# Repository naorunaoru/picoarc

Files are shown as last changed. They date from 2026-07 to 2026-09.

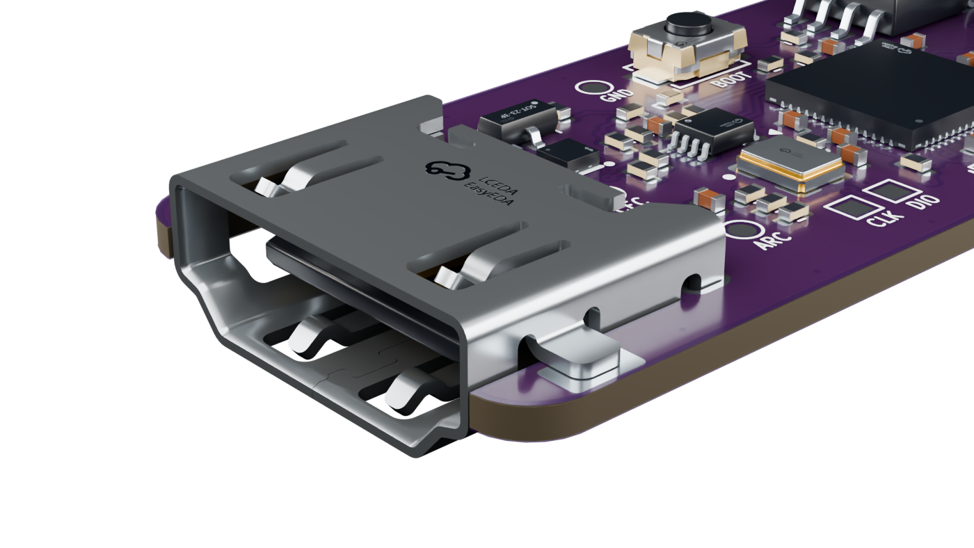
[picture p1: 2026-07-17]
assets/camera-studies/neutral-shadow-transparent/03-hdmi-macro.png

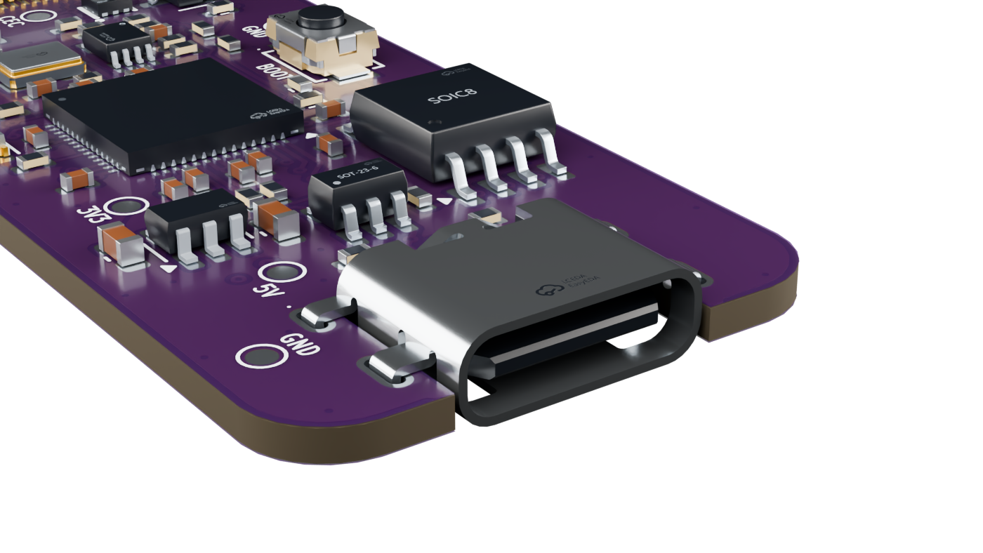
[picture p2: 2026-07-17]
assets/camera-studies/neutral-shadow-transparent/04-usbc-macro.png

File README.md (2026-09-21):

01-clean-isometric

# PicoARC

PicoARC is a device that appears to the host as a USB audio interface and passes through incoming audio as an S/PDIF-style stream to an ARC-compatible device. In simpler terms, this allows you to output audio from your computer to a soundbar or an ARC-capable receiver. It builds as USB Audio Class 1 by default for broad host compatibility; USB Audio Class 2 remains available as an opt-in target.

It also allows you to control the soundbar's volume. Somewhat. Because apparently supporting absolute volume control over CEC is not something that vendors are eager to implement.

Host volume and mute changes propagate to the soundbar in both USB modes. The
latest soundbar state is returned by subsequent USB control queries. UAC2 also
sends AudioControl change notifications; UAC1 has no notification endpoint, so
host volume controls generally remain stale after an on-device adjustment.
Host interfaces may ignore the UAC2 notifications as well.

Did I tell you it does HDMI-CEC too? Yes, it does, because it's required for ARC negotiation.

## Why?

There's no off-the-shelf way of doing this exact thing, surprisingly. The closest thing is using S/PDIF, which has limited bandwidth, sometimes incurs additional latency and definitely does not allow you to control the soundbar from the host.

## How does it work?

On the USB side, it acts as an audio interface, grabs the audio stream and passes it through.

On the HDMI side, it pretends to be a TV: responds to DDC queries with a plausible EDID, negotiates ARC with the connected audio system over CEC and drives the ARC line within the constraints defined by the HDMI 1.4 spec.

## Supported audio formats

- PCM at 32/44.1/48/88.2/96 kHz (higher sample rates are out of the question because RP2040 only has USB Full Speed)
- 16/20/24-bit

The optional UAC2 target additionally exposes separate IEC 61937 Dolby Digital
(AC-3) and DTS passthrough alternates. They are omitted from the default UAC1
target because host-driver support for Type III transport is inconsistent.

## Hardware

The PCB design lives under `hardware/`. The schematic source is written in
[Zener](https://docs.pcb.new/pages/spec), so `hardware/picoarc.zen` is the
schematic/netlist source of truth rather than a `.kicad_sch`; the KiCad layout
and JLCPCB production files are checked in alongside it.

See [hardware/README.md](hardware/README.md) for the hardware file map,
Zener/KiCad workflow, and the old hand-wired Pico prototype wiring.

## License

PicoARC uses a split license. Hardware design materials are licensed under
`CERN-OHL-W-2.0`, and firmware plus general project documentation are licensed
under `MIT`. See [LICENSE](LICENSE) for the exact scope and full license text
locations.

## Build requirements

- Git
- CMake and Ninja
- Arm GNU toolchain
- `picotool`

The Pico SDK and TinyUSB sources are pinned as git submodules under
`firmware/third_party`; builds do not use SDK copies installed on the host.
PicoARC uses Pico SDK 2.2.0 and upstream TinyUSB 0.21.0.

## Build

From this directory:

```sh
git submodule update --init --recursive
make build
```

This configures and builds both firmware variants:

```text
firmware/build-release/picoarc-release.uf2
firmware/build-debug/picoarc-debug.uf2
```

Those are UAC1 builds. To build the opt-in UAC2 target instead:

```sh
make build-uac2
```

Its artifacts use separate build directories and names so CMake and host USB
caches cannot mix the two personalities:

```text
firmware/build-release-uac2/picoarc-release-uac2.uf2
firmware/build-debug-uac2/picoarc-debug-uac2.uf2
```

UAC1 is the recommended full-speed target and is the mode tested for Windows
compatibility. Treat UAC2 as experimental on full-speed hosts; it is retained
for IEC 61937 and uses an adaptive OUT endpoint without explicit feedback. The
firmware follows the host's delivery rate by servoing the S/PDIF PIO clock from
the receive-buffer level.

The equivalent helper option is `--usb-audio-class uac2` (or `--uac uac2`),
for example `./picoarc build release --uac uac2`. Direct CMake builds can set
`-DPICOARC_USB_AUDIO_CLASS=uac2`; omitting the option selects UAC1.

By default PicoARC stops the ARC/S/PDIF carrier while USB audio is idle so the
soundbar can go to standby. To keep sending silence instead, which can prevent
short notification sounds from being swallowed while the soundbar wakes, edit
`firmware/src/picoarc_config.h` before building:

```c
#define PICOARC_IDLE_AUDIO_KEEPALIVE 1
```

Set it back to `0` for the default standby-friendly behavior.

The release variant is audio-only with logging compiled out. It waits for an
HDMI ARC device, completes ARC/SAD capability discovery, asks the soundbar for
its OSD name, and then enumerates as USB audio using that name when the soundbar
provides one. The debug variant keeps the USB serial log and reset interface
online for bring-up work, so it enumerates immediately with the default audio
descriptor.

## Host sanitizer tests

The host tests require CMake, Ninja, and a native Clang or GCC installation
with AddressSanitizer and UndefinedBehaviorSanitizer runtimes. They do not need
the Pico SDK, Arm compiler, or initialized submodules. Run them with the
default C compiler or select one before the first configure:

```sh
make test-sanitizers
CC=clang make test-sanitizers
```

The compiler selection is cached in `firmware/build-host-sanitizers`; remove
that generated directory before switching compilers. The tests compile the
same USB audio sample decoder used by the firmware and cover the supported
16-, 20-, and 24-bit subslots, including IEC 61937 words, unaligned byte input,
buffer bounds, and the maximum audio-task batch.

The RP2040 firmware remains on its normal embedded build path and is not
instrumented. Host tests cannot validate DMA and PIO timing, multicore races,
interrupt behavior, or flash-blackout behavior on the device.

## Flash

Connect the Pico over USB, then run:

```sh
make flash
```

The helper script builds the release firmware first, then uses `picotool` to
load and run the UF2. If the Pico is not detected, hold BOOTSEL while plugging
it in and run the command again.

To flash the optional UAC2 release build, use `make flash-uac2`.

## Monitor

To open the USB serial log:

```sh
make monitor
```

To build, flash, and then open the monitor in one step:

```sh
make run
```

This flashes the debug variant, because the release variant does not expose a
USB serial log.

`make run-uac2` does the same with the optional UAC2 debug build.

Press `Ctrl-]` to close the monitor.

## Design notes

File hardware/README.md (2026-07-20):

# PicoARC Hardware

The fab-ready PicoARC PCB design lives in this directory. The circuit is
authored with the [Zener](https://docs.pcb.new/pages/spec) toolchain from
[Diode](https://github.com/diodeinc/pcb), and the physical board layout is kept
as a generated/synced [KiCad](https://kicad.org/) project.

## Source of Truth

Zener is a Starlark-based hardware description language for PCB schematics. The
`pcb` CLI evaluates the `.zen` design, manages dependencies from `pcb.toml`,
assigns reference designators, validates the netlist, and generates/syncs KiCad
layout files.

In this repo, the `.zen` files are the schematic source of truth. There is no
separate `.kicad_sch` to edit:

- `picoarc.zen` is the top-level board schematic/netlist.
- `modules/` contains reusable schematic subcircuits for USB-C, power, HDMI
  ARC, and debug/status hardware.
- `components/` contains local RP2040 and flash component definitions.
- `footprints/` contains local symbols, footprints, and 3D models not taken
  directly from the upstream KiCad libraries.

Edit the Zen module tree when changing the circuit, then regenerate/sync the
KiCad layout from that source.

## Debug Probe Access

`TP_SWD` is a compact row of three 1.0 x 2.0 mm edge test pads on 1.5 mm pitch.
Connect it to Raspberry Pi Debug Probe using pogo pins or soldered leads. Its
target-side pinout is:

- pin 1: SWCLK / SC
- pin 2: GND
- pin 3: SWDIO / SD

The SWCLK and SWDIO pads currently connect directly to the RP2040. Target-side
100 ohm series termination is intentionally omitted while the board layout is
in flux and should be reconsidered before fabrication. The center ground pad
and the board's other solderable ground test pads use thermal-relief zone
connections to make hand soldering practical.

## Layout and Production Files

- `pcb.toml` is the Zener workspace/board manifest. It pins the board entry
  point, repository metadata, `pcb-version`, and KiCad library dependencies.
- `layout/layout.kicad_pro` is the KiCad project to open for board review.
- `layout/layout.kicad_pcb` is the checked-in PCB layout.
- `layout/layout.kicad_dru` contains KiCad design rules.
- `layout/jlcpcb/gerber/` contains the plotted Gerber/drill outputs.
- `layout/jlcpcb/production_files/` contains the current JLCPCB upload bundle:
  `GERBER-layout.zip`, `BOM-layout.csv`, and `CPL-layout.csv`.
- `jlcpcb-lcsc.csv` records JLCPCB/LCSC sourcing data used by the board.

## Zener/KiCad Workflow

Install the `pcb` shim using the
[upstream instructions](https://docs.pcb.new/pages/quickstart). The shim selects
the `pcbc` toolchain lane requested by `pcb.toml`; this repo currently requests
the `0.3` lane.

After changing the Zen schematic, run from this directory:

```sh
pcb sync
pcb build picoarc.zen
pcb layout picoarc.zen
```

`pcb sync` reconciles imports and dependency manifests. `pcb build` evaluates
and validates the Zener design. `pcb layout` regenerates/syncs the KiCad layout
project from the Zen netlist.

After that, open `layout/layout.kicad_pro` in KiCad for placement/routing
review, DRC, and fabrication exports. KiCad remains the tool for inspecting and
finishing the physical layout; Zener remains the tool for changing the circuit.

## Prototype Wiring

If you want to reproduce the old hand-wired Pico dev-board prototype instead,
the minimal wiring is:

- Pi Pico dev board
- HDMI breakout
- Few passives you probably have laying around
- 3.3 V <-> 5 V I2C level shifter for HDMI DDC/EDID (or not, if you're brave)

```text
Net CEC_BUS
  Pico 3V3 (pin 36)  -- R1 (27 kOhm) -- node CEC_BUS
  Pico GP3 (pin 5)   -- R2 (220 Ohm) -- node CEC_BUS
  node CEC_BUS                         -- HDMI pin 13

Net ARC_TX
  Pico GP2 (pin 4)   -- R3 (330 Ohm) -- node ATT_A
  node ATT_A         -- R4 (56 Ohm)  -- Pico GND
  node ATT_A         -- C1 (10 nF)   -- HDMI pin 14

Net HDMI_5V_FROM_SOUNDBAR
  HDMI pin 18        -- R5 (1 kOhm)   -- HDMI pin 19
  HDMI pin 18        -- R6 (68 kOhm)  -- node HDMI_5V_SENSE
  node HDMI_5V_SENSE                   -- Pico GP4 (pin 6)
  node HDMI_5V_SENSE -- R7 (100 kOhm) -- Pico GND

Net DDC_EDID
  HDMI pin 15 (SCL)  -- level shifter -- Pico GP7 (pin 10)
  HDMI pin 16 (SDA)  -- level shifter -- Pico GP6 (pin 9)

Net GND
  Pico GND (pin 38)                    -- HDMI pin 17
```

Note about DDC_EDID: while omitting a level shifter works as a bench-only direct
GPIO bodge, keep in mind that HDMI DDC is a 5 V bus and RP2040 IO is not exactly
5 V tolerant.

## License

The PicoARC hardware design materials in this directory are licensed under the
CERN Open Hardware Licence Version 2 - Weakly Reciprocal (`CERN-OHL-W-2.0`).
See [../LICENSE](../LICENSE) for the repository license notice and full license
text locations.

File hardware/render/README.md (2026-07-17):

# PicoARC product renders

The render pipeline treats `hardware/layout/layout.kicad_pcb` as the physical
source of truth. This is intentional: Zener owns the schematic/netlist, while
the checked-in KiCad PCB contains the hand-routed placement, tracks, zones,
board outline, and silkscreen used in the images.

Run from the repository root:

```sh
./hardware/render/render_pcb.py
```

The command exports the current routed PCB to a temporary STEP assembly,
refreshes the board inside `picoarc-hero.blend`, reapplies the pinned materials
and exact component models, and renders all six camera views to:

```text
assets/camera-studies/neutral-shadow-transparent/
```

The adjacent `render-manifest.json` uses repository-relative source paths and
output paths relative to the manifest. Generated PNGs and optionally saved
Blender scenes are stripped of host-specific path and runtime metadata.

The pinned default is:

- transparent RGBA background
- Neutral Shadow solder-mask/copper treatment
- neutral-loop product lighting
- Cycles with 64 samples and denoising
- 1400 x 788 PNG output
- the six named camera angles stored in the Blender template

Useful development overrides:

```sh
# Fast check of the first and HDMI views
./hardware/render/render_pcb.py --angles 1,3 --samples 16

# Render the optional charcoal-background variant
./hardware/render/render_pcb.py --background charcoal

# Save the refreshed Blender scene for inspection
./hardware/render/render_pcb.py --save-blend /tmp/picoarc-refreshed.blend
```

`render-config.json` pins the visual preset, output names, camera set, and the
baseline KiCad poses used to move the calibrated exact STEP replacements. If an
exact component is moved or rotated in KiCad, no Blender edit is necessary. If
one is moved to the opposite PCB side or its footprint/model origin changes,
the command stops and asks for that model to be recalibrated instead of
silently producing a wrong render.

Tool discovery uses `PATH` first and then the standard macOS application paths.
Use `--kicad-cli`, `--blender`, `KICAD_CLI`, or `BLENDER` to override them.

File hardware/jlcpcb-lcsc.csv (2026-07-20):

# JLCPCB LCSC overlay map for picoarc. Columns: kind | key | lcsc
# kind=mpn -> match a manufacturer part number from `pcb bom`
# kind=ref -> override by designator (wins over an mpn match)
# Seeded with the 8 ICs/connectors | then the passives/LED/MOSFET/crystal/switch (web-sourced
# from LCSC 2026-06-24 — VERIFY before ordering).
# ESD consolidation (2026-06-24): the former D2 PESD5V0L4UF (4-ch | SOT-886 | JLC shortfall +
# not LCSC-stocked) and D3 PESD5V0S2BT (2-ch) were replaced by a single 5-ch array
# (D2 D5V0M5B6LP16-7 | C445551) on the signal lines + a single TVS on the cable +5V.
# D3 cable-+5V TVS: H7VN10B (bidirectional) -> H7VH10U (UNIdirectional | C51898355
# cheaper) on 2026-06-25 — a DC rail wants a unidirectional TVS. Same R+O DFN1006-2L
# footprint (drop-in) | but polarity now matters: cathode->_HDMI_5V (verify in JLC preview).
# `make fab` WARNs and lists any still-unmapped part.
# --- ICs / connectors ---
mpn | RP2040 | C2040
mpn | PCA9306DCUR | C33196
mpn | W25Q16JVSSIQ | C131025
mpn | USBLC6-2SC6 | C7519
mpn | HC-HDMI0019T-3 | C7501810
mpn | GT-USB-7014G | C3019717
mpn | AP2112K-3.3TRG1 | C51118
# --- ESD protection ---
mpn | D5V0M5B6LP16-7 | C445551
mpn | H7VH10U | C51898355
# --- resistors (UNI-ROYAL 0402 | JLC Basic) ---
mpn | 0402WGF1000TCE | C25076
mpn | 0402WGF1001TCE | C11702
mpn | 0402WGF1002TCE | C25744
mpn | 0402WGF1003TCE | C25741
mpn | 0402WGF1200TCE | C25079
mpn | 0402WGF2003TCE | C25764
mpn | 0402WGF2200TCE | C25091
mpn | 0402WGF2201TCE | C25879
mpn | 0402WGF2202TCE | C25768
mpn | 0402WGF3300TCE | C25104
mpn | 0402WGF330JTCE | C25105
mpn | 0402WGF5101TCE | C25905
# --- capacitors ---
mpn | 0402CG101J500NT | C1546
mpn | 0402CG330J500NT | C1562
mpn | CL05A105KA5NQNC | C52923
mpn | CL05B103KB5NNNC | C15195
# next two are JLC Extended parts (per-part fee):
mpn | CL05B104KB54PNC | C307331
mpn | CL10A106MA8NRNC | C96446
# --- LED / MOSFET / crystal / switch ---
mpn | KT-0603R | C2286
mpn | 2N7002 | C8545
mpn | X322512MSB4SI | C9002
mpn | TS-1088-AR02016 | C720477

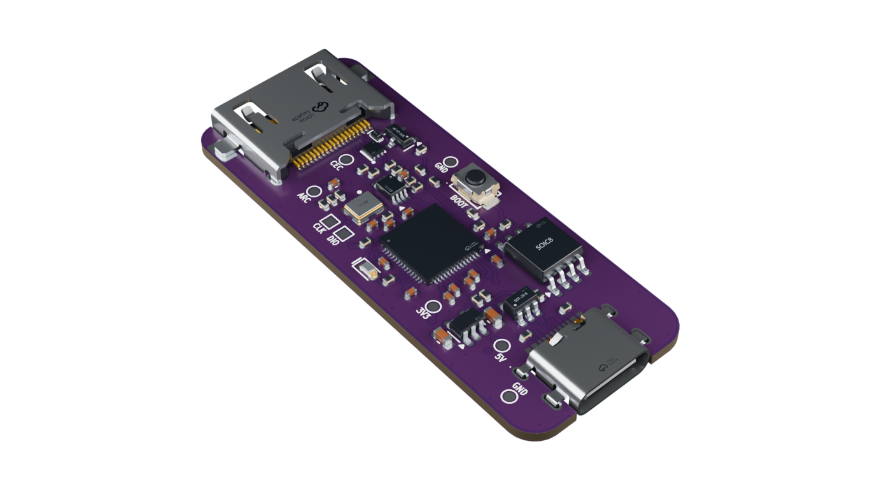
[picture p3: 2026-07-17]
assets/camera-studies/neutral-shadow-transparent/01-clean-isometric.png

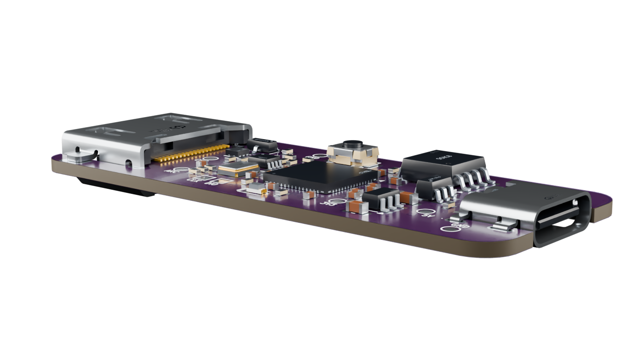
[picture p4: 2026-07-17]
assets/camera-studies/neutral-shadow-transparent/05-low-product.png

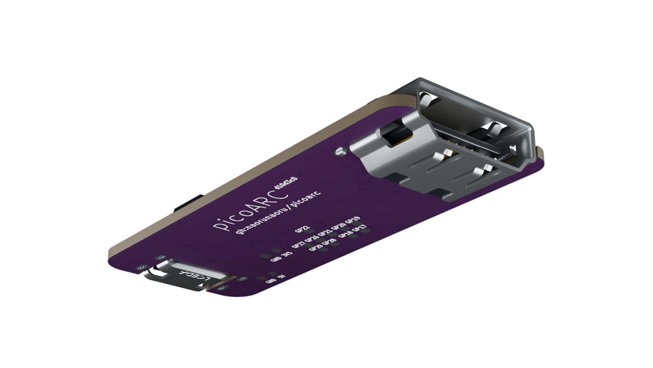
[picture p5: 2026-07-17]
assets/camera-studies/neutral-shadow-transparent/06-underside-grazing.png

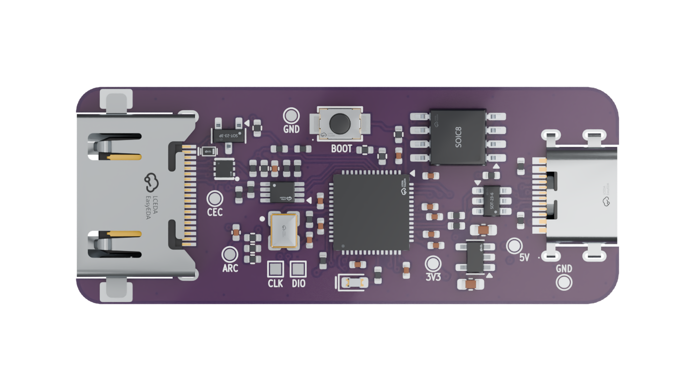
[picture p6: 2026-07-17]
assets/camera-studies/neutral-shadow-transparent/02-straight-overhead.png

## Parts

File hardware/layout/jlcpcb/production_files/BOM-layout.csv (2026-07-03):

Comment | Designator | Footprint | LCSC | Quantity
D5V0M5B6LP16-7 | D2 | DFN1616-6_L1.6-W1.6-P0.50-BL-EP | C445551 | 1
H7VH10U | D3 | SOD-882_L1.0-W0.6-BI | C7420372 | 1
TS-1088-AR02016 | SW1 | SW-SMD_L3.9-W3.0-P4.45 | C720477 | 1
0402WGF3300TCE | R3 | R_0402_1005Metric |  | 1
0402WGF1001TCE | R5 | R_0402_1005Metric |  | 1
RP2040 | U5 | QFN-56-1EP_7x7mm_P0.4mm_EP3.2x3.2mm |  | 1
0402WGF1200TCE | R15 | R_0402_1005Metric |  | 1
0402WGF2202TCE | R1 | R_0402_1005Metric |  | 1
CL05B104KB54PNC | C13 | C_0402_1005Metric |  | 1
0402WGF2201TCE | R10 | R_0402_1005Metric |  | 1
0402WGF1001TCE | R16 | R_0402_1005Metric |  | 1
CL05B104KB54PNC | C8 | C_0402_1005Metric |  | 1
CL05A105KA5NQNC | C7 | C_0402_1005Metric |  | 1
0402WGF1003TCE | R6 | R_0402_1005Metric |  | 1
CL05B104KB54PNC | C9 | C_0402_1005Metric |  | 1
CL05B104KB54PNC | C11 | C_0402_1005Metric |  | 1
0402WGF1002TCE | R20 | R_0402_1005Metric |  | 1
0402WGF1000TCE | R14 | R_0402_1005Metric |  | 1
0402WGF1001TCE | R23 | R_0402_1005Metric |  | 1
CL05B104KB54PNC | C12 | C_0402_1005Metric |  | 1
0402WGF2201TCE | R9 | R_0402_1005Metric |  | 1
0402CG330J500NT | C15 | C_0402_1005Metric |  | 1
0402CG101J500NT | C2 | C_0402_1005Metric |  | 1
0402CG330J500NT | C14 | C_0402_1005Metric |  | 1
CL05B104KB54PNC | C5 | C_0402_1005Metric |  | 1
CL05B104KB54PNC | C10 | C_0402_1005Metric |  | 1
0402WGF1003TCE | R7 | R_0402_1005Metric |  | 1
0402WGF1002TCE | R19 | R_0402_1005Metric |  | 1
0402WGF1001TCE | R4 | R_0402_1005Metric |  | 1
CL10A106MA8NRNC | C3 | C_0603_1608Metric |  | 1
CL05A105KA5NQNC | C6 | C_0402_1005Metric |  | 1
CL05B103KB5NNNC | C1 | C_0402_1005Metric |  | 1
AP2112K-3.3TRG1 | U2 | SOT-23-5 |  | 1
CL10A106MA8NRNC | C4 | C_0603_1608Metric |  | 1
2N7002 | Q1 | SOT-23 |  | 1
208658-1001 | J1 | HDMI_A_Molex_208658-1001_Horizontal |  | 1
0402WGF5101TCE | R18 | R_0402_1005Metric |  | 1
USBLC6-2SC6 | U3 | SOT-23-6 |  | 1
X322512MSB4SI | Y1 | Crystal_SMD_3225-4Pin_3.2x2.5mm |  | 1
0402WGF2200TCE | R2 | R_0402_1005Metric |  | 1
W25Q16JVSSIQ | U4 | SOIC-8_5.3x5.3mm_P1.27mm |  | 1
0402WGF330JTCE | R22 | R_0402_1005Metric |  | 1
0402WGF2003TCE | R12 | R_0402_1005Metric |  | 1
USB4105-GF-A-060 | J2 | USB_C_Receptacle_GCT_USB4105-xx-A_16P_TopMnt_Horizontal |  | 1
0402WGF1003TCE | R13 | R_0402_1005Metric |  | 1
0402WGF2201TCE | R11 | R_0402_1005Metric |  | 1
0402WGF2201TCE | R8 | R_0402_1005Metric |  | 1
0402WGF5101TCE | R17 | R_0402_1005Metric |  | 1
KT-0603R | D1 | LED_0603_1608Metric |  | 1
PCA9306DCTR | U1 | VSSOP-8_2.3x2mm_P0.5mm |  | 1
0402WGF330JTCE | R21 | R_0402_1005Metric |  | 1

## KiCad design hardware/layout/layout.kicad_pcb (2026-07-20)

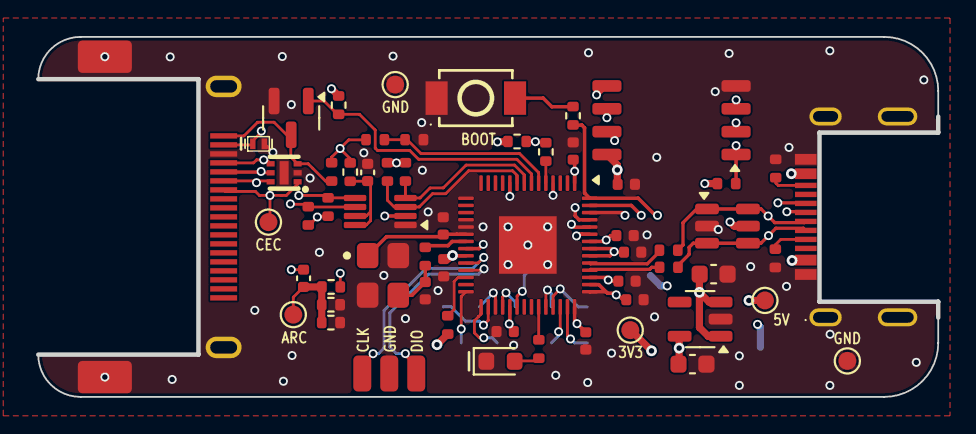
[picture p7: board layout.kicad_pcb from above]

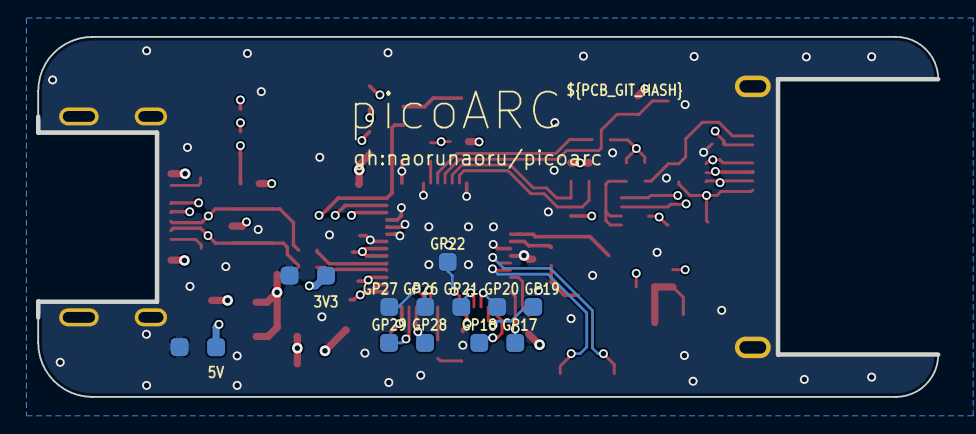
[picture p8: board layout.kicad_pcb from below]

Board: 4 copper layers, 50.0 x 20.0 mm, 72 parts (14 on the bottom side), 49 nets.

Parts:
C1: CL05B103KB5NNNC; C_0402_1005Metric
C2: 0402CG101J500NT; C_0402_1005Metric
C3, C4: CL10A106MA8NRNC; C_0603_1608Metric
C5, C8, C9, C10, C11, C12, C13: CL05B104KB54PNC; C_0402_1005Metric
C6, C7: CL05A105KA5NQNC; C_0402_1005Metric
C14, C15: 0402CG330J500NT; C_0402_1005Metric
D1: KT-0603R; LED_0603_1608Metric
D2: D5V0M5B6LP16-7; DFN1616-6_L1.6-W1.6-P0.50-BL-EP
D3: H7VH10U; SOD-882_L1.0-W0.6-BI
J1: HC-HDMI0019T-3; HDMI-SMD_HC-HDMI0019T-3_PicoARC_R6
J2: GT-USB-7014G; USB-C-SMD_GT-USB-7014D
Q1: 2N7002; SOT-23
R1: 0402WGF2202TCE; R_0402_1005Metric
R2: 0402WGF2200TCE; R_0402_1005Metric
R3: 0402WGF3300TCE; R_0402_1005Metric
R4, R5, R16, R23: 0402WGF1001TCE; R_0402_1005Metric
R6, R7, R13: 0402WGF1003TCE; R_0402_1005Metric
R8, R9, R10, R11: 0402WGF2201TCE; R_0402_1005Metric
R12: 0402WGF2003TCE; R_0402_1005Metric
R14: 0402WGF1000TCE; R_0402_1005Metric
R15: 0402WGF1200TCE; R_0402_1005Metric
R17, R18: 0402WGF5101TCE; R_0402_1005Metric
R19, R20: 0402WGF1002TCE; R_0402_1005Metric
R21, R22: 0402WGF330JTCE; R_0402_1005Metric
SW1: TS-1088-AR02016; SW-SMD_L3.9-W3.0-P4.45
TP1, TP2, TP3, TP4, TP5, TP6, TP7, TP8, TP9, TP10, TP11, TP12, TP13, TP14: ?; TestPad_1.0x1.0mm_RoundRect
TP15: ?; SWD_EdgePads_1x03_P1.50mm
TP16, TP17, TP18, TP19, TP20, TP21: ?; TestPoint_Pad_D1.0mm
U1: PCA9306DCUR; VSSOP-8_2.3x2mm_P0.5mm
U2: AP2112K-3.3TRG1; SOT-23-5
U3: USBLC6-2SC6; SOT-23-6
U4: W25Q16JVSSIQ; SOIC-8_5.3x5.3mm_P1.27mm
U5: RP2040; QFN-56-1EP_7x7mm_P0.4mm_EP3.2x3.2mm
Y1: X322512MSB4SI; Crystal_SMD_3225-4Pin_3.2x2.5mm

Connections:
ARC_TX: R3.1, U5.4
ATT_A: C1.1, R3.2, R14.1, R15.1, TP18.1
BOOTSEL_SW: R16.2, SW1.1
CEC_BUS: R2.1, U5.5
CEC_NODE: D2.1, J1.13, R1.2, R2.2, TP19.1
DBG.STATUS_LED_A: D1.2, R4.2
DDC_SCL: R8.1, U1.3, U5.9
DDC_SCL_5V: D2.5, J1.15, R10.1, U1.6
DDC_SDA: R9.1, U1.4, U5.8
DDC_SDA_5V: D2.4, J1.16, R11.1, U1.5
GND: C2.2, C3.2, C4.2, C5.2, C6.2, C7.2, C8.2, C9.2, C10.2, C11.2, C12.2, C13.2, C14.2, C15.2, D1.1, D2.2, D2.7, D3.2, J1.17, J1.SH, J2.A1, J2.A12, J2.B1, J2.B12, J2.S1, Q1.2, R7.2, R14.2, R15.2, R17.2, R18.2, SW1.2, TP3.1, TP4.1, TP15.2, TP20.1, TP21.1, U1.1, U2.2, U3.2, U4.4, U5.19, U5.57, Y1.2, Y1.4
GP17: TP5.1, U5.28
GP18: TP6.1, U5.29
GP19: TP7.1, U5.30
GP20: TP8.1, U5.31
GP21: TP9.1, U5.32
GP22: TP10.1, U5.34
GP26: TP11.1, U5.38
GP27: TP12.1, U5.39
GP28: TP13.1, U5.40
GP29: TP14.1, U5.41
HDMI._ARC14: C1.2, D2.6, J1.14
HDMI._HDMI_5V: D3.1, J1.18, R5.1, R6.1, R10.2, R11.2, R12.1
HDMI._HPD: D2.3, J1.19, Q1.3, R5.2
HDMI._VREF2_EN: C2.1, R12.2, U1.7, U1.8
HDMI_5V_SENSE: R6.2, R7.1, U5.6
HPD_GATE: Q1.1, R13.1, U5.7
QSPI_CLK: U4.6, U5.52
QSPI_CS: R16.1, R19.1, U4.1, U5.56
QSPI_IO0: U4.5, U5.53
QSPI_IO1: U4.2, U5.55
QSPI_IO2: U4.3, U5.54
QSPI_IO3: U4.7, U5.51
RUN: R20.1, U5.26
STATUS_LED: R4.1, U5.37
SWD_SWCLK: TP15.1, U5.24
SWD_SWDIO: TP15.3, U5.25
USBC.CC1: J2.A5, R17.1
USBC.CC2: J2.B5, R18.1
USB_D_N: J2.A7, J2.B7, R21.2, U3.3, U3.4
USB_D_P: J2.A6, J2.B6, R22.2, U3.1, U3.6
U_MCU.RP_USB_D_N: R21.1, U5.46
U_MCU.RP_USB_D_P: R22.1, U5.47
U_MCU._R_OSC: C15.1, R23.1, Y1.3
U_MCU.oscpair_XIN: C14.1, U5.20, Y1.1
U_MCU.oscpair_XOUT: R23.2, U5.21
VDD_1V1: C6.1, C8.1, C9.1, U5.23, U5.45, U5.50
VDD_3V3: C4.1, C5.1, C7.1, C10.1, C11.1, C12.1, C13.1, R1.1, R8.2, R9.2, R13.2, R19.2, R20.2, TP1.1, TP16.1, U1.2, U2.5, U4.8, U5.1, U5.10, U5.22, U5.33, U5.42, U5.43, U5.44, U5.48, U5.49
VDD_5V: C3.1, J2.A4, J2.A9, J2.B4, J2.B9, TP2.1, TP17.1, U2.1, U2.3, U3.5

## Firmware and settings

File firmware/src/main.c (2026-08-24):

#include <stdio.h>

#include "arc.h"
#include "cec.h"
#include "ddc_edid.h"
#include "hardware/gpio.h"
#include "hardware/pwm.h"
#include "hardware/watchdog.h"
#include "picoarc_config.h"
#include "picoarc_log.h"
#include "pico/stdlib.h"
#include "spdif.h"
#include "tusb.h"
#include "usb_audio.h"
#include "usb_descriptors.h"

#define STATUS_LED_PWM_WRAP 255

typedef enum {
    ADAPTER_STATE_BOOT,
    ADAPTER_STATE_WAIT_HDMI,
    ADAPTER_STATE_CEC_SCAN,
    ADAPTER_STATE_CEC_DISCOVER,
    ADAPTER_STATE_ARC_INIT,
    ADAPTER_STATE_QUERY_CAPS,
    ADAPTER_STATE_USB_ATTACH,
    ADAPTER_STATE_USB_IDLE,
    ADAPTER_STATE_USB_STREAMING,
    ADAPTER_STATE_USB_DETACH,
    ADAPTER_STATE_USB_RECOVERY,
#if PICOARC_DEBUG_USB
    ADAPTER_STATE_DEBUG_USB,
#endif
} adapter_state_t;

typedef enum {
    STATUS_LED_OFF,
    STATUS_LED_WAIT_HDMI,
    STATUS_LED_WAIT_USB,
} status_led_mode_t;

static absolute_time_t usb_recovery_reconnect_at;

static void cec_yield_pump(void) {
    tud_task();
    usb_audio_task();
}

static spdif_mode_t idle_spdif_mode(void) {
#if PICOARC_IDLE_AUDIO_KEEPALIVE
    return SPDIF_MODE_SILENCE;
#else
    return SPDIF_MODE_OFF;
#endif
}

#if PICOARC_HPD_GATE_ENABLE
static void hpd_gate_hold(unsigned int gate_pin) {
    gpio_init(gate_pin);
    gpio_put(gate_pin, true);
    gpio_set_dir(gate_pin, GPIO_OUT);
    printf("hpd: holding low through GP%u gate\n", gate_pin);
}

static void hpd_gate_release(unsigned int gate_pin) {
    gpio_put(gate_pin, false);
    printf("hpd: released GP%u gate\n", gate_pin);
}
#endif

static const char *adapter_state_name(adapter_state_t state) {
    switch (state) {
    case ADAPTER_STATE_BOOT:
        return "boot";
    case ADAPTER_STATE_WAIT_HDMI:
        return "wait-hdmi";
    case ADAPTER_STATE_CEC_SCAN:
        return "cec-scan";
    case ADAPTER_STATE_CEC_DISCOVER:
        return "cec-discover";
    case ADAPTER_STATE_ARC_INIT:
        return "arc-init";
    case ADAPTER_STATE_QUERY_CAPS:
        return "query-caps";
    case ADAPTER_STATE_USB_ATTACH:
        return "usb-attach";
    case ADAPTER_STATE_USB_IDLE:
        return "usb-idle";
    case ADAPTER_STATE_USB_STREAMING:
        return "usb-streaming";
    case ADAPTER_STATE_USB_DETACH:
        return "usb-detach";
    case ADAPTER_STATE_USB_RECOVERY:
        return "usb-recovery";
#if PICOARC_DEBUG_USB
    case ADAPTER_STATE_DEBUG_USB:
        return "debug-usb";
#endif
    default:
        return "unknown";
    }
}

static void adapter_set_state(adapter_state_t *state, adapter_state_t next) {
    if (*state == next) {
        return;
    }

    printf("adapter: %s -> %s\n", adapter_state_name(*state), adapter_state_name(next));
    *state = next;
}

static void adapter_task(adapter_state_t *state, bool *usb_attached) {
    if (usb_audio_take_recovery_request()) {
        usb_audio_stop_streaming();
        if (*usb_attached) {
            tud_disconnect();
            *usb_attached = false;
        }
        usb_recovery_reconnect_at = make_timeout_time_ms(PICOARC_USB_RECOVERY_DISCONNECT_MS);
        printf("adapter: forcing USB re-enumeration after stalled audio stream\n");
        adapter_set_state(state, ADAPTER_STATE_USB_RECOVERY);
    }

#if PICOARC_DEBUG_USB
    if (*state == ADAPTER_STATE_DEBUG_USB) {
        usb_audio_task();
        return;
    }
#endif

    const bool hdmi_connected = arc_hdmi_connected();
    const bool audio_system_found = arc_cec_audio_system_found();
    const bool arc_initiated = arc_is_initiated();
    const bool caps_ready = arc_audio_caps_ready();
    const bool usb_ready = arc_ready_for_usb();

    if (*state >= ADAPTER_STATE_USB_ATTACH && *state <= ADAPTER_STATE_USB_STREAMING && !usb_ready) {
        adapter_set_state(state, ADAPTER_STATE_USB_DETACH);
    }

    switch (*state) {
    case ADAPTER_STATE_BOOT:
        adapter_set_state(state, ADAPTER_STATE_WAIT_HDMI);
        break;

    case ADAPTER_STATE_WAIT_HDMI:
        if (hdmi_connected) {
            adapter_set_state(state, ADAPTER_STATE_CEC_SCAN);
        }
        break;

    case ADAPTER_STATE_CEC_SCAN:
        if (!hdmi_connected) {
            adapter_set_state(state, ADAPTER_STATE_WAIT_HDMI);
        } else if (audio_system_found) {
            adapter_set_state(state, ADAPTER_STATE_CEC_DISCOVER);
        }
        break;

    case ADAPTER_STATE_CEC_DISCOVER:
        if (!hdmi_connected) {
            adapter_set_state(state, ADAPTER_STATE_WAIT_HDMI);
        } else if (!audio_system_found) {
            adapter_set_state(state, ADAPTER_STATE_CEC_SCAN);
        } else if (arc_system_audio_enabled() || arc_initiated) {
            adapter_set_state(state, ADAPTER_STATE_ARC_INIT);
        }
        break;

    case ADAPTER_STATE_ARC_INIT:
        if (!hdmi_connected) {
            adapter_set_state(state, ADAPTER_STATE_WAIT_HDMI);
        } else if (!audio_system_found) {
            adapter_set_state(state, ADAPTER_STATE_CEC_SCAN);
        } else if (arc_initiated) {
            adapter_set_state(state, ADAPTER_STATE_QUERY_CAPS);
        }
        break;

    case ADAPTER_STATE_QUERY_CAPS:
        if (!hdmi_connected) {
            adapter_set_state(state, ADAPTER_STATE_WAIT_HDMI);
        } else if (usb_ready) {
            adapter_set_state(state, ADAPTER_STATE_USB_ATTACH);
        } else if (!arc_initiated) {
            adapter_set_state(state, ADAPTER_STATE_ARC_INIT);
        } else if (!caps_ready) {
            break;
        }
        break;

    case ADAPTER_STATE_USB_ATTACH:
        if (!*usb_attached) {
            tud_connect();
            *usb_attached = true;
            printf("adapter: USB audio attached to host\n");
        }
        adapter_set_state(state, ADAPTER_STATE_USB_IDLE);
        break;

    case ADAPTER_STATE_USB_IDLE:
        usb_audio_task();
        if (usb_audio_is_streaming()) {
            adapter_set_state(state, ADAPTER_STATE_USB_STREAMING);
        }
        break;

    case ADAPTER_STATE_USB_STREAMING:
        usb_audio_task();
        if (!usb_audio_is_streaming()) {
            adapter_set_state(state, ADAPTER_STATE_USB_IDLE);
        }
        break;

    case ADAPTER_STATE_USB_DETACH:
        usb_audio_stop_streaming();
        if (*usb_attached) {
            tud_disconnect();
            *usb_attached = false;
            printf("adapter: USB audio detached from host\n");
        }
        if (!hdmi_connected) {
            adapter_set_state(state, ADAPTER_STATE_WAIT_HDMI);
        } else if (!audio_system_found) {
            adapter_set_state(state, ADAPTER_STATE_CEC_SCAN);
        } else if (!arc_initiated) {
            adapter_set_state(state, ADAPTER_STATE_ARC_INIT);
        } else {
            adapter_set_state(state, ADAPTER_STATE_QUERY_CAPS);
        }
        break;

    case ADAPTER_STATE_USB_RECOVERY:
        if (!time_reached(usb_recovery_reconnect_at)) {
            break;
        }
#if PICOARC_DEBUG_USB
        tud_connect();
        *usb_attached = true;
        printf("adapter: USB audio reattached to host\n");
        adapter_set_state(state, ADAPTER_STATE_DEBUG_USB);
#else
        adapter_set_state(state, ADAPTER_STATE_QUERY_CAPS);
#endif
        break;

#if PICOARC_DEBUG_USB
    case ADAPTER_STATE_DEBUG_USB:
        break;
#endif
    }
}

static void status_led_set_gpio(uint led_pin, bool *led_on, bool on) {
    if (*led_on == on) {
        return;
    }

    *led_on = on;
    gpio_put(led_pin, on);
}

static void status_led_enable_pwm(uint led_pin) {
    const uint slice = pwm_gpio_to_slice_num(led_pin);
    const uint channel = pwm_gpio_to_channel(led_pin);

    gpio_set_function(led_pin, GPIO_FUNC_PWM);
    pwm_set_wrap(slice, STATUS_LED_PWM_WRAP);
    pwm_set_chan_level(slice, channel, 0);
    pwm_set_enabled(slice, true);
}

static void status_led_disable_pwm(uint led_pin) {
    const uint slice = pwm_gpio_to_slice_num(led_pin);
    const uint channel = pwm_gpio_to_channel(led_pin);

    pwm_set_chan_level(slice, channel, 0);
    pwm_set_enabled(slice, false);
    gpio_set_function(led_pin, GPIO_FUNC_SIO);
    gpio_set_dir(led_pin, GPIO_OUT);
    gpio_put(led_pin, false);
}

static uint16_t status_led_breath_level(uint32_t elapsed_ms) {
    const uint32_t phase_ms = elapsed_ms % PICOARC_STATUS_LED_WAIT_USB_BREATHE_MS;
    const uint32_t half_ms = PICOARC_STATUS_LED_WAIT_USB_BREATHE_MS / 2;
    const uint32_t ramp_ms = phase_ms < half_ms ? phase_ms : PICOARC_STATUS_LED_WAIT_USB_BREATHE_MS - phase_ms;
    const uint32_t linear = (ramp_ms * STATUS_LED_PWM_WRAP) / half_ms;

    return (uint16_t)((linear * linear) / STATUS_LED_PWM_WRAP);
}

static void status_led_update_breath(uint led_pin, uint32_t started_ms) {
    const uint slice = pwm_gpio_to_slice_num(led_pin);
    const uint channel = pwm_gpio_to_channel(led_pin);
    const uint32_t elapsed_ms = to_ms_since_boot(get_absolute_time()) - started_ms;

    pwm_set_chan_level(slice, channel, status_led_breath_level(elapsed_ms));
}

static void status_led_task(uint led_pin,
                            status_led_mode_t mode,
                            status_led_mode_t *active_mode,
                            bool *led_on,
                            absolute_time_t *next_transition,
                            uint32_t *breath_started_ms) {
    if (*active_mode != mode) {
        if (*active_mode == STATUS_LED_WAIT_USB) {
            status_led_disable_pwm(led_pin);
            *led_on = false;
        }

        *active_mode = mode;

        if (mode == STATUS_LED_WAIT_USB) {
            *breath_started_ms = to_ms_since_boot(get_absolute_time());
            status_led_enable_pwm(led_pin);
            status_led_update_breath(led_pin, *breath_started_ms);
        } else {
            status_led_set_gpio(led_pin, led_on, mode == STATUS_LED_WAIT_HDMI);
            *next_transition = make_timeout_time_ms(PICOARC_STATUS_LED_WAIT_HDMI_BLINK_MS);
        }
        return;
    }

    if (mode == STATUS_LED_OFF) {
        if (*led_on) {
            status_led_set_gpio(led_pin, led_on, false);
        }
        return;
    }

    if (mode == STATUS_LED_WAIT_USB) {
        status_led_update_breath(led_pin, *breath_started_ms);
        return;
    }

    if (absolute_time_diff_us(get_absolute_time(), *next_transition) <= 0) {
        status_led_set_gpio(led_pin, led_on, !*led_on);
        *next_transition = make_timeout_time_ms(PICOARC_STATUS_LED_WAIT_HDMI_BLINK_MS);
    }
}

int main(void) {
    const bool watchdog_reboot = watchdog_caused_reboot();
    watchdog_enable(PICOARC_WATCHDOG_TIMEOUT_MS, true);
    tusb_init();
#if !PICOARC_DEBUG_USB
    tud_disconnect();
#endif
#if PICOARC_LOGGING
    stdio_init_all();
#endif

    // GP5 is an active-high FET gate: high holds HDMI HPD low, low releases it.
    // Keep HPD deasserted until the EDID responder is installed below.
#if PICOARC_HPD_GATE_ENABLE
    hpd_gate_hold(PICOARC_HPD_GATE_PIN);
#endif

    // Bring up the audio/CEC hardware before pumping tud_task. The host can
    // issue class-specific audio control transfers as soon as enumeration
    // completes, so the S/PDIF path must be ready before USB traffic is served.
    spdif_start(PICOARC_SPDIF_PIN);
    spdif_set_mode(idle_spdif_mode());
#if PICOARC_DDC_EDID_ENABLE
    ddc_edid_init(PICOARC_DDC_EDID_SDA_PIN, PICOARC_DDC_EDID_SCL_PIN);
#endif
#if PICOARC_HPD_GATE_ENABLE
    hpd_gate_release(PICOARC_HPD_GATE_PIN);
#endif
    arc_init(PICOARC_CEC_PIN, PICOARC_HDMI_5V_PIN);
    cec_set_yield(cec_yield_pump);

    const uint led_pin = PICO_DEFAULT_LED_PIN;
    gpio_init(led_pin);
    gpio_set_dir(led_pin, GPIO_OUT);
    gpio_put(led_pin, false);

    printf("\nPicoARC bring-up\n");

    if (watchdog_reboot) {
        printf("adapter: recovered from watchdog reset\n");
    }

    printf("spdif: GP%d 48k stereo %s\n", PICOARC_SPDIF_PIN, spdif_mode_name(spdif_get_mode()));
    printf("adapter: idle audio policy=%s\n", PICOARC_IDLE_AUDIO_POLICY);
#if PICOARC_DEBUG_USB
    printf("adapter: debug USB stays online; audio streaming remains ARC/SAD gated\n");
#else
    printf("adapter: release USB waits for HDMI ARC capabilities and OSD name before enumeration\n");
#endif

    absolute_time_t next_led_transition = make_timeout_time_ms(PICOARC_STATUS_LED_WAIT_HDMI_BLINK_MS);
    uint32_t led_breath_started_ms = 0;
    bool led_on = false;
    status_led_mode_t led_mode = STATUS_LED_OFF;
    bool usb_attached = PICOARC_DEBUG_USB;
    adapter_state_t adapter_state =
#if PICOARC_DEBUG_USB
        ADAPTER_STATE_DEBUG_USB;
#else
        ADAPTER_STATE_BOOT;
#endif

    while (true) {
        tud_task();
#if PICOARC_DDC_EDID_ENABLE
        ddc_edid_task();
#endif
        arc_task();
        adapter_task(&adapter_state, &usb_attached);

        const bool hdmi_connected = arc_hdmi_connected();
        const bool usb_enumerated = usb_attached && tud_mounted();
        const status_led_mode_t next_led_mode =
            !hdmi_connected ? STATUS_LED_WAIT_HDMI : (!usb_enumerated ? STATUS_LED_WAIT_USB : STATUS_LED_OFF);
        status_led_task(led_pin, next_led_mode, &led_mode, &led_on, &next_led_transition, &led_breath_started_ms);

        watchdog_update();
        tight_loop_contents();
    }
}

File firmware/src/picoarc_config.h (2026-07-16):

#ifndef PICOARC_CONFIG_H
#define PICOARC_CONFIG_H

// Board-level GPIO assignments.
#define PICOARC_SPDIF_PIN 2
#define PICOARC_CEC_PIN 3
#define PICOARC_HDMI_5V_PIN 4
#define PICOARC_HDMI_5V_DEBOUNCE_MS 100

// Active-high FET gate: high holds HDMI HPD low, low releases HPD.
#define PICOARC_HPD_GATE_ENABLE 1
#define PICOARC_HPD_GATE_PIN 5
#define PICOARC_HPD_REPLUG_LOW_MS 200

// Set to 1 to keep sending silence while USB audio is idle.
// Set to 0 to stop the ARC/S/PDIF carrier while idle so the soundbar can standby.
#define PICOARC_IDLE_AUDIO_KEEPALIVE 0

// Status LED user-visible timing.
#define PICOARC_STATUS_LED_WAIT_HDMI_BLINK_MS 1000
#define PICOARC_STATUS_LED_WAIT_USB_BREATHE_MS 2400

// Recover when a host selects a streaming alternate setting but does not keep
// delivering isochronous audio. Keep the hardware watchdog long enough for
// synchronous CEC transactions while still recovering a wedged main loop.
#define PICOARC_USB_STREAM_PACKET_TIMEOUT_MS 1500
#define PICOARC_USB_RECOVERY_DISCONNECT_MS 500
#define PICOARC_WATCHDOG_TIMEOUT_MS 8000

// Answer HDMI DDC EDID reads from the RP2040 through the board-level I2C
// translator. HDMI DDC is a 5V bus; do not connect pins 15/16 directly to
// RP2040 GPIO outside a bench-only bodge.
#define PICOARC_DDC_EDID_ENABLE 1
#define PICOARC_DDC_EDID_SDA_PIN 6
#define PICOARC_DDC_EDID_SCL_PIN 7
#define PICOARC_DDC_EDID_CEC_READY_BYTES 256
#define PICOARC_DDC_EDID_CEC_SETTLE_MS 750
#define PICOARC_DDC_EDID_CEC_NO_READ_TIMEOUT_MS 3000

// Optional CEC audio probing
#define PICOARC_CEC_QUERY_EXTRA_SADS 0

#if PICOARC_IDLE_AUDIO_KEEPALIVE
#define PICOARC_IDLE_AUDIO_POLICY "keepalive"
#else
#define PICOARC_IDLE_AUDIO_POLICY "standby"
#endif

#endif

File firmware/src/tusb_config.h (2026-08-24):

#ifndef PICOARC_TUSB_CONFIG_H
#define PICOARC_TUSB_CONFIG_H

#include "usb_descriptors.h"

#ifndef CFG_TUSB_MCU
#error CFG_TUSB_MCU must be defined
#endif

#ifndef CFG_TUSB_OS
#define CFG_TUSB_OS OPT_OS_PICO
#endif

#ifndef CFG_TUSB_DEBUG
#define CFG_TUSB_DEBUG 0
#endif

#define CFG_TUSB_RHPORT0_MODE OPT_MODE_DEVICE

#define CFG_TUD_ENABLED 1
#define CFG_TUD_MAX_SPEED OPT_MODE_FULL_SPEED
#define CFG_TUSB_MEM_SECTION
#define CFG_TUSB_MEM_ALIGN __attribute__((aligned(4)))

#define CFG_TUD_ENDPOINT0_SIZE 64

#define CFG_TUD_CDC PICOARC_DEBUG_USB
#define CFG_TUD_AUDIO 1
#define CFG_TUD_HID 0
#define CFG_TUD_MSC 0
#define CFG_TUD_MIDI 0
#define CFG_TUD_VENDOR 0

#define CFG_TUD_CDC_RX_BUFSIZE 256
#define CFG_TUD_CDC_TX_BUFSIZE 256

#define CFG_TUD_AUDIO_ENABLE_EP_OUT 1
#define CFG_TUD_AUDIO_ENABLE_FEEDBACK_EP PICOARC_AUDIO_HAS_FEEDBACK_EP
#define CFG_TUD_AUDIO_ENABLE_INTERRUPT_EP PICOARC_AUDIO_HAS_INTERRUPT_EP

#define CFG_TUD_AUDIO_FUNC_1_MAX_SAMPLE_RATE PICOARC_AUDIO_SAMPLE_RATE_MAX
#define CFG_TUD_AUDIO_FUNC_1_N_CHANNELS_RX 2
// Sized for the largest streaming alts (20/24-bit packed, 3 bytes per sample).
// The 16-bit alt fits in the same buffers with bytes to spare.
#define CFG_TUD_AUDIO_FUNC_1_N_BYTES_PER_SAMPLE_RX 3
#define CFG_TUD_AUDIO_FUNC_1_RESOLUTION_RX 24
#define CFG_TUD_AUDIO_FUNC_1_EP_OUT_SZ_MAX TUD_AUDIO_EP_SIZE(false, CFG_TUD_AUDIO_FUNC_1_MAX_SAMPLE_RATE, CFG_TUD_AUDIO_FUNC_1_N_BYTES_PER_SAMPLE_RX, CFG_TUD_AUDIO_FUNC_1_N_CHANNELS_RX)
#define CFG_TUD_AUDIO_FUNC_1_EP_OUT_SW_BUF_SZ (8 * CFG_TUD_AUDIO_FUNC_1_EP_OUT_SZ_MAX)
#define CFG_TUD_AUDIO_CTRL_BUF_SZ 64

#endif

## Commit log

2026-05-19 fix: rm player persona experiments
    [cec.c, main.c]
2026-05-19 feat(cec): TX via PIO+DMA with yield-aware wait
    Move CEC transmission and the per-byte ACK slot onto a single PIO
    state machine fed by DMA. The SM runs at 1 MHz so every loop
    iteration is exactly 1 us; per-action dispatch overhead is
    constant for the chained command order the encoder produces, so
    on-the-wire timing is independent of DMA timing.
    ACK sampling now happens inside the PIO at 1050 us after the
    fall edge, with the sample word streamed back via a second DMA
    channel into an RX buffer. The CPU's only wait loop calls a
    yield callback (tud_task + usb_audio_task) so USB SOF servicing
    and the spdif ring keep running through multi-byte frames -
    fixes the audio dropouts that came from the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
    [cec.c, main.c]
2026-05-19 feat(usb-audio): add 48k/24-bit streaming alt
    UAC2 streaming interface now exposes alt 1 (48 kHz / 16-bit PCM,
    the original v1 format) and alt 2 (48 kHz / 24-bit packed PCM,
    3-byte samples) alongside the mandatory alt 0. The host picks at
    SET_INTERFACE time; the audio task parses 2- or 3-byte
    little-endian samples accordingly and feeds spdif a single
    24-bit-left-aligned int32 representation either way.
    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
2026-05-19 feat(arc): bidirectional CEC volume/mute sync
    Host-side feature unit (mute + volume RW) drives soundbar volume
    over CEC, and unsolicited <Report Audio Status> from the soundbar
    drives the host's reported volume back via tud_audio_int_write
    on the AC interrupt EP.
    Outbound flow tries absolute volume first with
    <Set Audio Volume Level> (CEC 2.0 opcode 0x73). If the soundbar
    feature-aborts or doesn't reflect the requested level back in
    the next <Report Audio Status>, fall back to stepping
    <User Control Pressed/Released> Volume-Up/Down events until the
    reported volume matches the target. Mute follows the same
    pattern via Mute key.
    CEC version response bumped from 1.4 to 2.0 so the soundbar
    wil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
2026-05-19 feat(usb-audio): advertise 48 kHz and 96 kHz sample rates
    The UAC2 clock source now reports two discrete rates via
    GET RANGE on AUDIO_CS_CTRL_SAM_FREQ. On SET CUR the device
    switches between them at runtime by reprogramming the spdif
    PIO clkdiv: half-bit rate is rate_hz * 128 (6.144 MHz at 48k,
    12.288 MHz at 96k). The S/PDIF block layout is rate-agnostic so
    only the PIO clock changes — the BMC encoder, DMA structure,
    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
2026-05-19 fix(audio): init spdif before USB starts handling control transfers
    macOS issues SET CUR on the clock source during enumeration to
    restore the last-selected sample rate, well before main()
    reached spdif_start. The audio callback ran with spdif_pio
    still NULL, so pio_sm_set_clkdiv wrote to NULL + 0xC8 (in flash)
    instead of PIO0.SM0.CLKDIV — silently failing while still
    returning success from the control transfer. The device then
    streamed at 48 kHz while macOS pushed 96 kHz worth of samples
    per second, overflowing the ring at ~47 k frames/sec drops.
    Move spdif_start and arc_init ahead of wait_for_console_attach
    so all hardware globals are set before tud_task processes any
    class request. Add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
    [main.c]
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2026-05-21 Make idle ARC carrier configurable
    Add a firmware config header for the idle audio keepalive policy, support an off S/PDIF mode when idle, and stop the idle CEC probe loop once ARC is ready.
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2026-05-29 hardware: add diodeinc/kicad + stdlib dependencies
    Adds github.com/diodeinc/kicad@0.2.2 as a direct dependency so that
    RP2040 and other KiCad reference modules resolve via the @kicad/... import
    prefix. Also adds hardware/.gitignore to exclude pcb tool cache artifacts.
2026-05-29 hardware: add configured RP2040 reference module
    Instantiates the @kicad/MCU_RaspberryPi/RP2040.zen reference module as
    U_MCU with firmware-matching GPIO assignments (ARC_TX/CEC_BUS/HDMI_5V_SENSE
    on gpio2-4, DDC_SDA/SCL on gpio6-7, STATUS_LED on gpio25), crystal, BOOTSEL
    button, and SWD test points; 23 components total.
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2026-05-29 hardware: generate initial KiCad layout (60 footprints, unrouted)
    [layout.kicad_pcb]
2026-05-29 hardware: add MPNs to authored components (clears 6/9 BOM errors, enables per-module schematic view)
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2026-05-31 hardware: DRC relaxation pass — 4-layer planes, pours, net classes, cost rules, clean silk
    Checkpoint of the bring-up layout before the RP2040-module refactor.
    - Planes/pours: In1=GND plane, In2=VDD_3V3 plane, F/B GND pours, GND
    stitch-via grid + QFN exposed-pad thermal vias.
    - Resolved real DRC: track/pad clearances (incl. QSPI_IO3<->C7 via a
    small C7 nudge), dangling vias/tracks, starved thermals
    (min_resolved_spokes 2->1), isolated copper.
    - Custom rules (layout.kicad_dru): 0.13mm fine-pitch clearance inside
    U2 (PCA9306) and U5 (RP2040 QFN) courtyards.
    - Net classes: Power (VDD_*) 0.4mm, USB diff-pair 0.25/0.20mm.
    - Project: resolve ${PCB_NAME}/${PCB_VERSION} title-block vars,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
    [layout.kicad_pcb]
2026-05-31 docs: design spec — custom RP2040 module + all-Basic BOM re-spec
    Approved design for owning the RP2040 support circuit (clone-and-trim of the
    vendored module), pinning all passives to JLCPCB Basic parts, dropping the unused
    GPIO header/breakouts, and adding bidirectional ARC/HDMI-5V ESD. Checkpoint before
    implementation.
2026-05-31 docs: implementation plan — custom RP2040 module + all-Basic BOM
    Milestone plan with a critical post-re-sync layout-preservation gate (revert to
    6ed3f1d if the layout is wiped) and high-value-first sequencing (J2/SW1 footprint swaps
    isolated last so a footprint-sourcing snag can't block the core all-Basic + ESD work).
2026-05-31 hardware: own RP2040 support circuit + all-Basic BOM + ARC/5V ESD (source)
    Source refactor (layout re-sync follows separately):
    - components/RP2040.zen: local clone-and-trim of the vendored module — identical
    child names/footprints/topology (placement-preserving), every passive pinned to
    a JLCPCB Basic MPN, RP2040 chip part=RP2040(C2040), USB series 27->33ohm, GPIO
    header + unused-GPIO breakouts dropped, only used GPIOs exposed.
    - Power.zen: inlined LDO (AP2112K-3.3) so caps are Basic-pinned; dropped the
    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
2026-05-31 docs: resolved JLCPCB Basic parts reference (RP2040 refactor)
    Verified Basic MPNs/LCSC# for the all-Basic re-spec, plus the value-subs and the
    ESD/LDO/switch resolutions. Companion to the implementation plan.
2026-05-31 hardware: keep small Omron B3U-1000P for SW1 (no small JLC-Basic tact exists)
    Only JLC-Basic SMD tact is the 5.1x5.1mm TS-1187A; all small ones (B3U 3x2.5mm,
    EVQ 3.6x3.5mm) are Extended. For a rarely-pressed BOOTSEL button the ~$3 feeder fee
    beats sacrificing ~5x5mm of board, so revert SW1 to the original small B3U. Also means
    SW1's footprint now matches the placed layout (one fewer part to reconcile).
2026-05-31 hardware: SW1 -> TS-1088-AR02016 (4x3mm JLC-Basic tact) via easyeda2kicad footprint
    The 4x3mm TS-1088 is the small JLC-Basic SMD tact (C720477, free). No KiCad lib
    footprint exists, so generated one with easyeda2kicad (--lcsc_id=C720477) and added
    it locally at footprints/picoarc.pretty/. Uses the generic Switch:SW_Push symbol
    (2 pads, 1/2) + the local footprint; stripped the broken /tmp 3D-model ref. pcb build
    clean (59 components). SW1 now Basic -> Extended floor back to ~8.
2026-06-12 hardware: shrink to 50x22mm, backside GPIO pads, DRC/netclass cleanup
    - board outline 50.0x22.0mm: fits JLCPCB's cheap <=50x50 4-layer tier
    - 14 backside expansion pads (1x1mm roundrect): GP17-22, GP26-29 (all
    4 ADC), 3V3/5V/GND; net-name silk labels instead of TP designators
    - netclasses: drop *USB_D_* shadow pattern (pair now routes true 90R
    0.1867/0.127), RP_USB_D_* stubs into 90Ohm Diff, 50Ohm SE 0.2mm
    - kicad_dru: retarget fine-pitch pad rule U2->U1 (refdes shuffle),
    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
    [layout.kicad_pcb]
2026-06-13 hardware: pre-production fixes (PCA9306 bias, HPD gate FET, BOOTSEL 1k, 33pF xtal caps)
    Schematic review findings, all new parts JLC-Basic:
    - PCA9306: EN+VREF2 shorted and biased from cable 5V via R12 200k + C2 100pF
    per TI SCPS113O (was: VREF2 hard-tied to 5V, EN to 3V3 - pass-FET damage
    risk and below the VREF1+0.6V enable minimum)
    - HPD: Q1 2N7002 holds HPD low (gate pulled to 3V3 by R13 100k) until
    firmware drives new GP5/HPD_GATE low once the EDID slave is ready;
    unpowered board falls back to passive assert via R5
    - BOOTSEL: R_BOOT 1k between QSPI_CS and SW1 per RP2040 design guide
    - crystal: 15pF -> 33pF load caps to match YXC X322512MSB4SI CL=20pF
    - cosmetics: D_ESD K3/K4 comm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
    [layout.kicad_pcb]
2026-06-13 fix: center USB connector to the board
    [layout.kicad_pcb]
2026-06-13 fix: reroute ATT_A in a less roundabout way
    [layout.kicad_pcb]
2026-06-13 fix: no more vias in pads, @ivanlevsky should be proud
    [layout.kicad_pcb]
2026-06-13 fix: I like to move it move it
    [layout.kicad_pcb]
2026-06-13 fix: angular USB diff pair go!
    [layout.kicad_pcb]
2026-06-14 hardware: QSPI reroute, board shrink, things moved here and there
    [layout.kicad_pcb]
2026-06-24 feat(fab): module scaffold + version/filename stamp
    - Module scaffold with standard library imports
    - Module-level path constants for board, project, overlays
    - compute_stamp() generates version stamps with optional dirty flag
    - output_names() produces output filename paths for gerbers, BOM, CPL, DRC
2026-06-24 feat(fab): LCSC overlay parsing + seed map
    [jlcpcb-lcsc.csv]
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2026-06-24 feat(fab): orchestration, CLI, DRC gate + integration test
    Adds main() with --skip-drc/--gerbers-only/--no-zip flags, run/run_drc/
    summarize_drc/export_gerbers/export_drill/export_pos/run_pcb_bom/write_csv/
    zip_dir helpers, and __main__ guard. IntegrationSmokeTest exercises the
    full pipeline against the real board (skip-drc mode); 21/21 tests pass.
2026-06-24 fix(fab): run pcb bom from hardware/ so make fab works from repo root
2026-06-24 hardware: add backside silkscreen
    [layout.kicad_pcb]
2026-06-24 fix(fab): group BOM by MPN identity + real footprints so distinct parts don't merge
    build_bom grouped by (value,package,lcsc); pcb bom leaves those blank for ICs/
    connectors, so D2/Q1/SW1 (different parts) collapsed into one row and every IC
    shipped a blank Comment+Footprint. Group by MPN (the orderable identity) instead,
    fall back Comment->MPN and Footprint->pos Package column. Export pos once and reuse
    for BOM + CPL.
2026-06-24 feat(fab): fill LCSC overlay map for passives/LED/MOSFET/crystal/switch
    Web-sourced from LCSC (2026-06-24, needs ordering confirmation). 22 MPNs mapped;
    make fab now warns on only D2 (PESD5V0L4UF 4-ch ESD), which LCSC/JLCPCB does not
    stock — substitute or supply externally.
    [jlcpcb-lcsc.csv]
2026-06-24 hardware: consolidate HDMI ESD into 5-ch array + single +5V TVS
    Replace the JLC-shortfall PESD5V0L4UF (4-ch, SOT-886, not LCSC-stocked) and
    the PESD5V0S2BT (2-ch) with one 5-channel bidirectional array, D5V0M5B6LP16-7
    (C445551), covering CEC/HPD/DDC_SDA_5V/DDC_SCL_5V/ARC, plus a single
    bidirectional TVS H5VL10B (C7420372) on the cable +5V. Both LCSC-stocked.
    - Add local footprints + symbols (array I/O pins renamed IO1/IO3/IO4/IO5/IO6
    since the LCSC-generated symbol names all five "I/O", unaddressable by the
    pins-by-name binding) and .wrl 3D models.
    - Drop the D3 SOD-882 pin-1 silk circle that clipped pad-1 mask.
    - Update jlcpcb-lcsc overlay; re-sync layout. DRC 0/0, make fab clean.
    [jlcpcb-lcsc.csv, layout.kicad_pcb]
2026-06-24 hardware: replace HDMI 5V TVS
    [jlcpcb-lcsc.csv, layout.kicad_pcb]
2026-06-24 feat(fab): JLCPCB CPL rotation correction layer
    remap_cpl passed KiCad rotations through verbatim; KiCad's footprint 0-deg
    orientation disagrees with JLCPCB's part library for SOT-23/VSSOP/SOIC/QFN, so
    parts (U1/U2/U3...) rendered rotated in JLC's preview. Add a footprint-regex +
    per-designator correction table (hardware/jlcpcb-rotations.csv, community-standard
    seeds) applied at CPL generation; connectors/easyeda footprints left uncorrected
    pending preview verification.
    [jlcpcb-rotations.csv]
2026-06-25 hardware: enforce JLCPCB via limits in DRC
    Add two custom rules to layout.kicad_dru so the `make fab` strict-DRC gate
    catches sub-spec vias before ordering (the issue JLC flagged on order
    12939101A_Y2):
    - JLCPCB_min_via_diameter: via diameter >= 0.45mm (JLC process minimum)
    - JLCPCB_small_via_annular_no_kelvin: annular ring >= 0.125mm for holes
    <= 0.2mm, i.e. >= 0.45mm pad on a 0.2mm drill -- below this JLC forces a
    paid 4-wire Kelvin test. Scoped to small holes so it doesn't false-flag
    the 0.5/0.3mm stitching vias (0.1mm ring), which JLC accepts.
    Kept in .kicad_dru (not .kicad_pro design_settings): KiCad rewrites the
    .kicad_pro from memory on quit and would silently revert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
2026-06-25 hardware: replace D3 +5V TVS with unidirectional H7VH10U
    Swap the cable +5V TVS from H7VN10B (bidirectional, C20615788) to H7VH10U
    (R+O, unidirectional, C51898355). A unidirectional TVS is the correct
    topology for a DC rail, and it's cheaper. Same R+O DFN1006-2L/SOD-882
    package -> drop-in footprint, no layout re-sync needed.
    VRWM 7V / breakdown 7.5V / clamp 15V clears the <=5.3V rail with margin;
    500nA leakage is negligible for the R6/R7 100k sense divider, and the 15V
    clamp is fine since everything on _HDMI_5V is resistor-isolated.
    Polarity now matters: cathode (C, pad 1) -> _HDMI_5V, anode (A, pad 2) ->
    GND. D3 gets no jlcpcb-rotations.csv correction (easyeda/LCSC footprints
    already matc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
    [jlcpcb-lcsc.csv]
2026-06-25 hardware/layout: fix sub-spec vias, add orientation silk, D3 cathode
    Resolve JLCPCB order 12939101A_Y2 + assembly-orientation cleanup:
    - 3 stitching vias were 0.2mm drill / 0.4mm pad (0.1mm annular), which JLC
    flagged for a mandatory paid 4-wire Kelvin test. Resized to the standard
    0.3mm/0.5mm stitching via and refilled all zones (the larger pad needs
    the GND/VDD planes to pull back, or DRC throws clearance errors).
    - Added F.SilkS orientation indicators to the polarized 2-pin parts whose
    marks the earlier silk-strip pass had removed: D1 LED cathode bar,
    Y1 crystal pin-1 dot, D3 TVS cathode bar (placed outside the courtyards;
    DRC stays clean). ICs/Q1 (POLY pin-1)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
    [layout.kicad_pcb]
2026-06-25 hardware: adjust layout, add jlcpcb export to gitignore
    [layout.kicad_pcb]
2026-07-03 hardware: remove hand-rolled fab export tooling (moved to hardware/fab-export)
    Superseded by the kicad-jlcpcb-tools plugin. The fab.py exporter, its tests, and
    the rotation-correction table are preserved on branch hardware/fab-export. The
    curated jlcpcb-lcsc.csv MPN->LCSC map is kept here as reference. Makefile fab
    target and the fab/ gitignore entry reverted.
    [jlcpcb-rotations.csv]
2026-07-03 hardware: track kicad-jlcpcb-tools output, drop stale jclcpcb gitignore
    Version-control the plugin's JLCPCB production files (gerbers, drill, BOM, CPL,
    project.db) under hardware/layout/jlcpcb/, and remove the (mistyped, now-unneeded)
    layout/jclcpcb/ ignore entry.
    [BOM-layout.csv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]
2026-07-08 hardware: swap J1/J2 to recessed mid-mount connectors on 1.2mm stack
    Replace the generic top-mount connectors with sunk-board (沉板) parts
    whose bodies sit in an Edge.Cuts cutout, minimising enclosure height:
    - J1 HDMI: Molex 208658-1001 -> Hong Cheng HC-HDMI0019T-3 (C7501810)
    - J2 USB-C: GCT USB4105-GF-A -> G-Switch GT-USB-7014G (C3019717)
    Board thinned to 1.2mm with an explicit 4-layer stackup config, matching
    the connectors' rated thickness. Adds hand-verified custom footprints
    (with cutouts integrated into the board outline) and their 3D models,
    and updates the jlcpcb-lcsc MPN->LCSC overlay.
    Layout re-synced and brought to a clean DRC (0 violations, 0 unconnected):
    - silk refere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
    [jlcpcb-lcsc.csv, layout.kicad_pcb]
2026-07-15 Fix full-speed UAC2 feedback and recovery
    [main.c, picoarc_config.h, tusb_config.h]
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2026-07-16 Fix ARC recovery after HDMI hotplug
    [cec.c, picoarc_config.h]
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2026-07-20 hardware: add picoprobe debug connector
    [layout.kicad_pcb]
2026-07-20 hardware: refine SWD pad routing
    [layout.kicad_pcb]
2026-07-20 hardware: use board-level thermal overrides
    [layout.kicad_pcb]
2026-07-20 Update flash LCSC sourcing code
    [jlcpcb-lcsc.csv]
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2026-10-20 Limit USB audio sample rates to soundbar capabilities
    Build advertised rates from the connected soundbar’s SAD capabilities and validate host rate selections against them. Refresh descriptors on capability changes and select a supported initial rate.
    Cover UAC1/UAC2 descriptors and control requests, soundbar swaps, missing capabilities, and unsupported formats with sanitizer tests.
2026-10-20 Send CEC replies when release logging is disabled
    Move eight reply sends out of printf arguments so release builds still complete ARC negotiation and answer CEC requests when logging is compiled out.
2026-10-20 Initialize submodules for host sanitizer tests
    The sample-rate tests compile real TinyUSB headers, so the sanitizer workflow must initialize submodules on clean runners.
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
